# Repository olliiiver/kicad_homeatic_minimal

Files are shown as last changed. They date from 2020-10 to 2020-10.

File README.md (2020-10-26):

## Homematic minimal PCB

A minimal PCB to build hardware devices for Homematic / BidCoS networks.

PINs (A0x - D0x, GND, 3v3) are compatible to 2.54mm prototype perfboards.

Upload is possible via Serial (FTDI,etc) and ISP (J3).

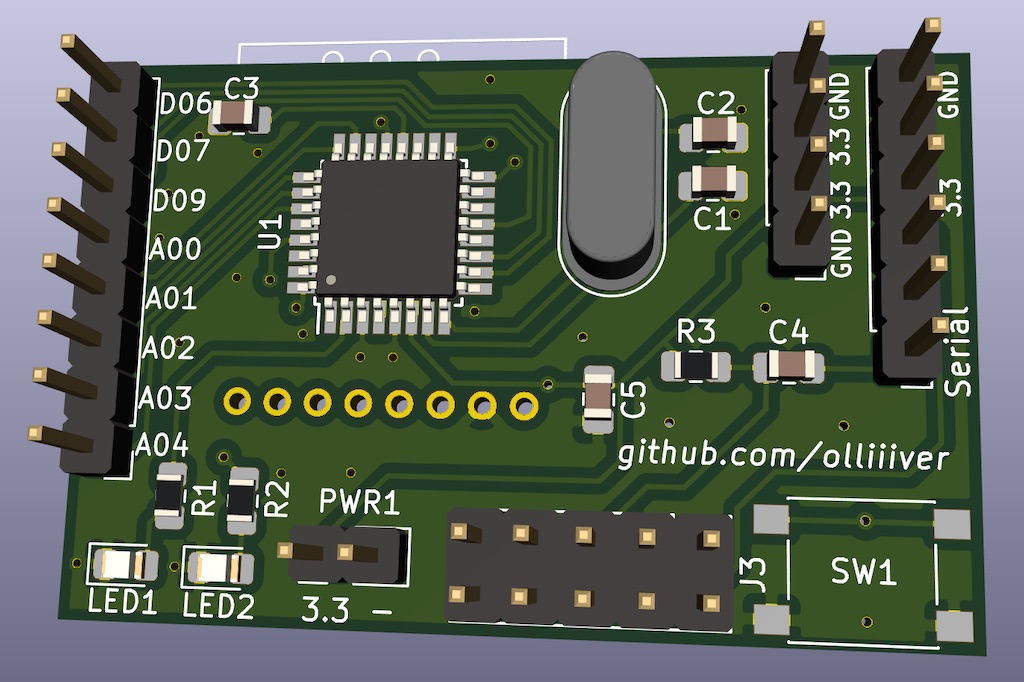
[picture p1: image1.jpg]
RENDERED


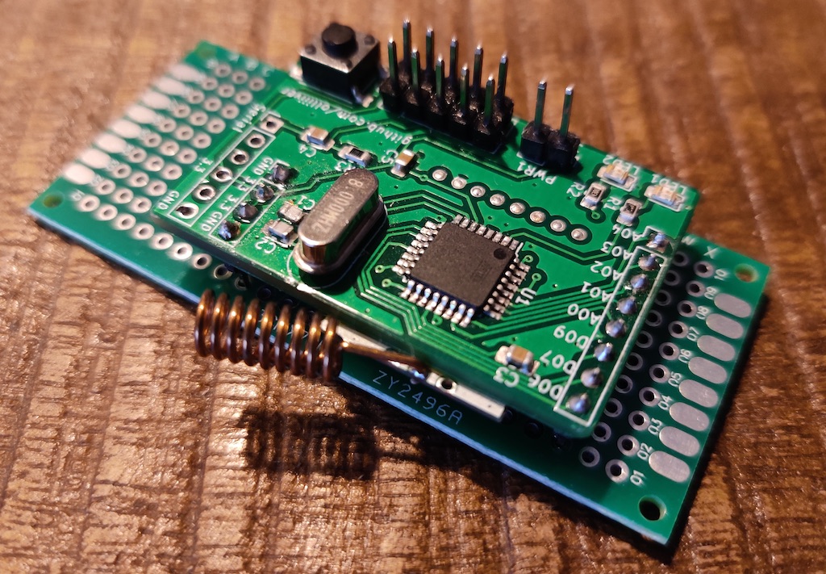
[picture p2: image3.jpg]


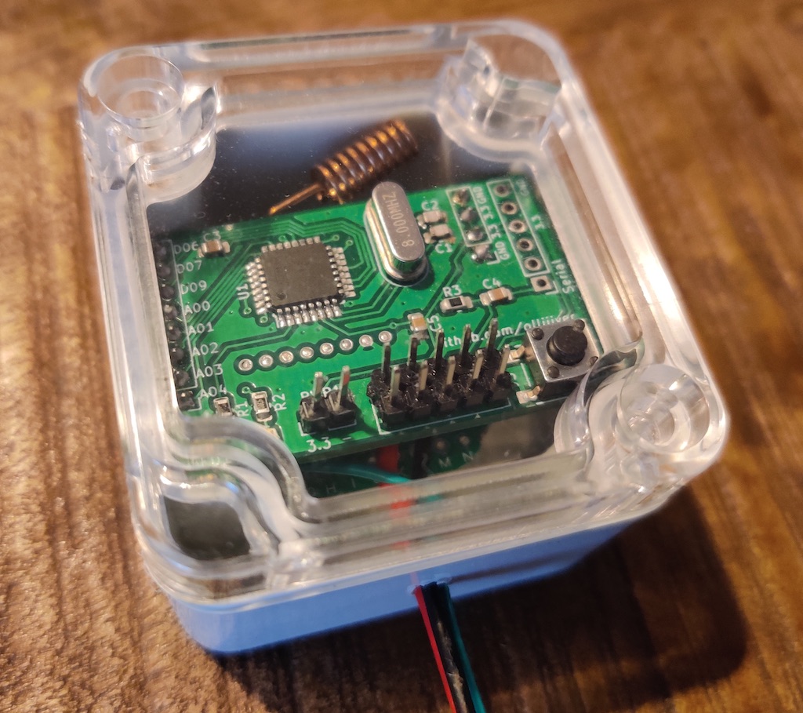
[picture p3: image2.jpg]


## BOM

- Case: RND 455-00192
  https://www.reichelt.de/polycarbonate-box-w-clear-lid-rnd-455-00192-p193406.html

- ATmega328P-AU
  http://ww1.microchip.com/downloads/en/DeviceDoc/Atmel-7810-Automotive-Microcontrollers-ATmega328P_Datasheet.pdf
  https://www.reichelt.de/atmega-avr-risc-controller-tqfp-32-atmega-328p-au-p119684.html
  
- Switch: RND 210-00204
  https://www.reichelt.de/pcb-tactile-switches-rnd-210-00204-p226425.html
  
- C 0805: 22 pF, 100pF
  https://www.reichelt.de/mlcc-0805-22-pf-200-v-5-rnd-1500805n2203-p226114.html
    
- LED 0805
  https://www.reichelt.de/led-smd-0805-green-7-1-mcd-160-oso-lgr971-p231718.html

  - R 0805: 330 Ohm, 1k Ohm, etc

  - CC1101 module from ebay

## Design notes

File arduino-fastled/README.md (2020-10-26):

## Implementation to use WS2801 stripes as a Homematic dimmer device

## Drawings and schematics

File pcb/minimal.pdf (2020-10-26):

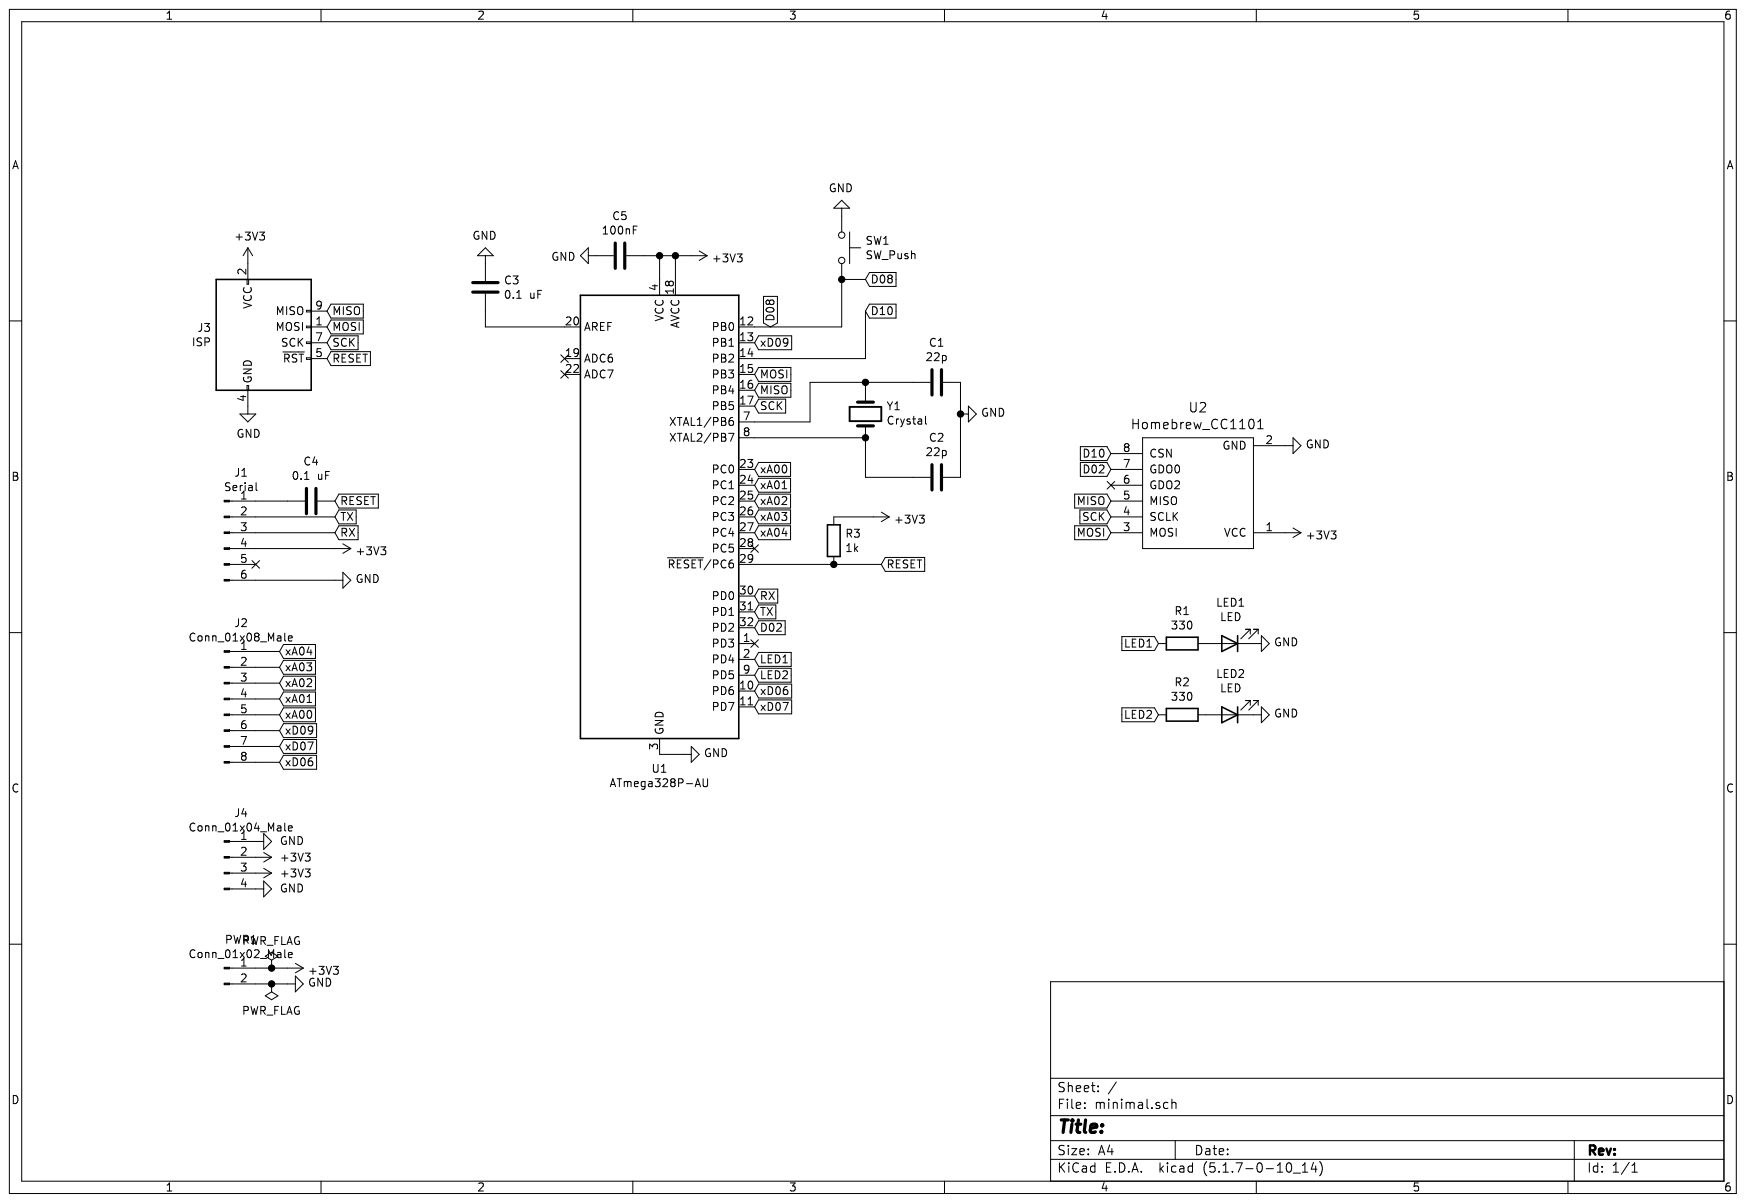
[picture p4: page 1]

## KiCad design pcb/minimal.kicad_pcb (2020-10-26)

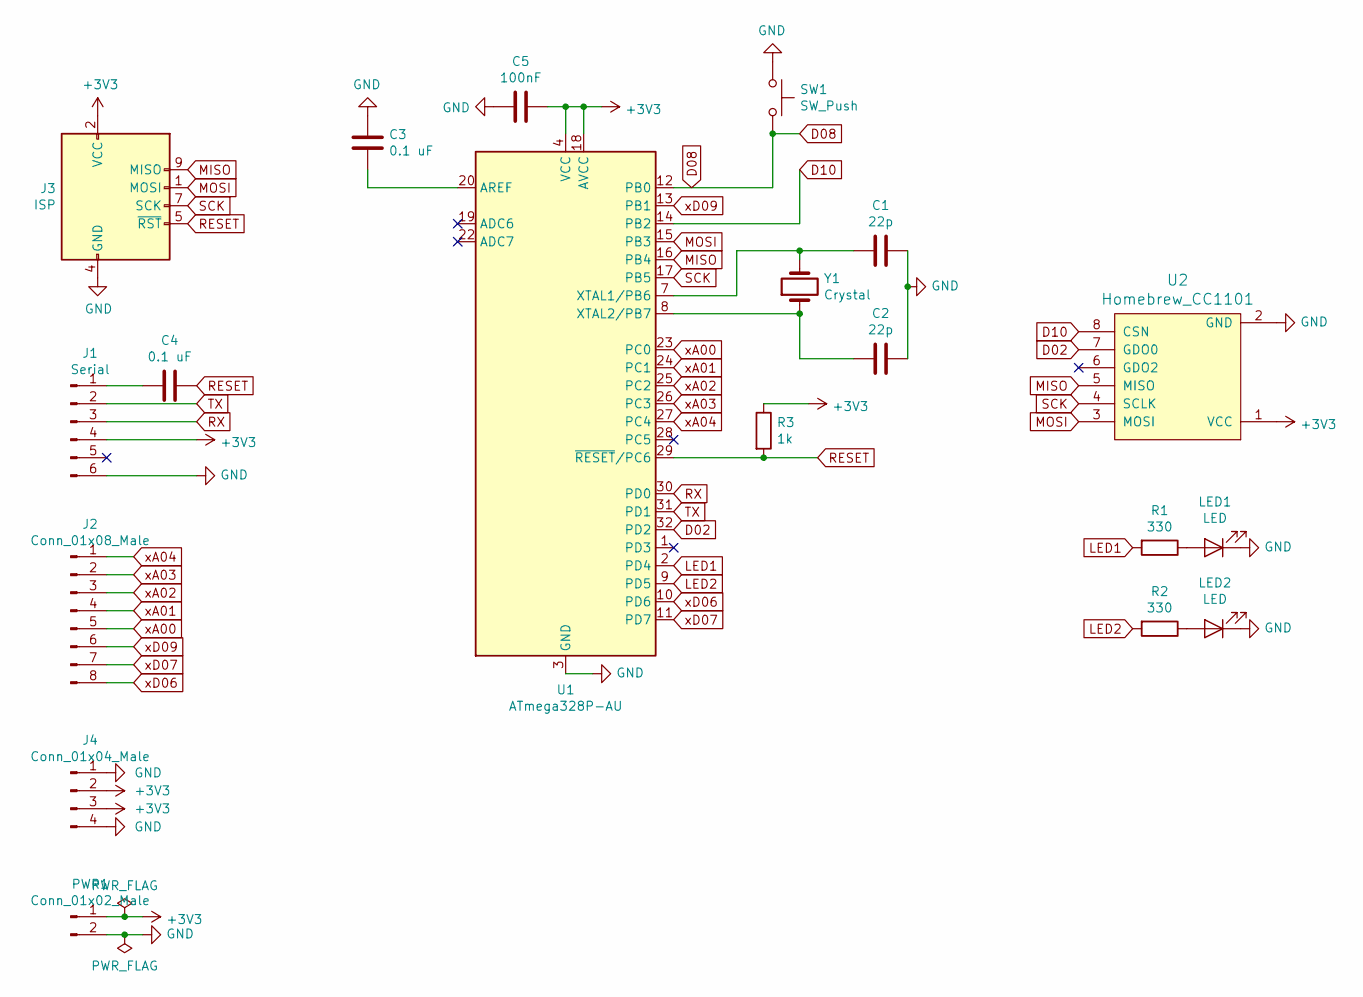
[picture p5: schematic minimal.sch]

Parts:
C1, C2: 22p; C_0805_2012Metric_Pad1.15x1.40mm_HandSolder
C3, C4: 0.1 uF; C_0805_2012Metric_Pad1.15x1.40mm_HandSolder
C5: 100nF; C_0805_2012Metric_Pad1.15x1.40mm_HandSolder
J1: Serial; PinHeader_1x06_P2.54mm_Vertical
J2: Conn_01x08_Male; PinHeader_1x08_P2.54mm_Vertical
J3: ISP; PinHeader_2x05_P2.54mm_Vertical
J4: Conn_01x04_Male; PinHeader_1x04_P2.54mm_Vertical
LED1, LED2: LED; LED_0805_2012Metric_Pad1.15x1.40mm_HandSolder
PWR1: Conn_01x02_Male; PinHeader_1x02_P2.54mm_Vertical
R1, R2: 330; R_0805_2012Metric_Pad1.15x1.40mm_HandSolder
R3: 1k; R_0805_2012Metric_Pad1.15x1.40mm_HandSolder
SW1: SW_Push; SW_Push_1P1T_NO_6x6mm_H9.5mm
U1: ATmega328P-AU; TQFP-32_7x7mm_P0.8mm
U2: Homebrew_CC1101; cc1101
Y1: Crystal; Crystal_HC49-4H_Vertical

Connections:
+3V3: C5.1, J1.4, J3.2 (VCC), J4.2, J4.3, PWR1.1, R3.1, U1.4 (VCC), U1.6 (VCC), U1.18 (AVCC), U2.1 (VCC)
D02: U1.32 (PD2), U2.7 (GDO0)
D08: SW1.2, U1.12 (PB0)
D10: U1.14 (PB2), U2.8 (CSN)
GND: C1.1, C2.1, C3.1, C5.2, J1.6, J3.4 (GND), J3.6 (GND), J3.8 (GND), J3.10 (GND), J4.1, J4.4, LED1.1 (K), LED2.1 (K), PWR1.2, SW1.1, U1.3 (GND), U1.5 (GND), U1.21 (GND), U2.2 (GND)
LED1: R1.2, U1.2 (PD4)
LED2: R2.2, U1.9 (PD5)
MISO: J3.9 (MISO), U1.16 (PB4), U2.5 (MISO)
MOSI: J3.1 (MOSI), U1.15 (PB3), U2.3 (MOSI)
unnamed: C1.2, U1.7 (XTAL1/PB6), Y1.2
unnamed: C2.2, U1.8 (XTAL2/PB7), Y1.1
unnamed: C3.2, U1.20 (AREF)
unnamed: C4.2, J1.1
unnamed: LED1.2 (A), R1.1
unnamed: LED2.2 (A), R2.1
RESET: C4.1, J3.5 (~RST), R3.2, U1.29 (~RESET~/PC6)
RX: J1.3, U1.30 (PD0)
SCK: J3.7 (SCK), U1.17 (PB5), U2.4 (SCLK)
TX: J1.2, U1.31 (PD1)
xA00: J2.5, U1.23 (PC0)
xA01: J2.4, U1.24 (PC1)
xA02: J2.3, U1.25 (PC2)
xA03: J2.2, U1.26 (PC3)
xA04: J2.1, U1.27 (PC4)
xD06: J2.8, U1.10 (PD6)
xD07: J2.7, U1.11 (PD7)
xD09: J2.6, U1.13 (PB1)

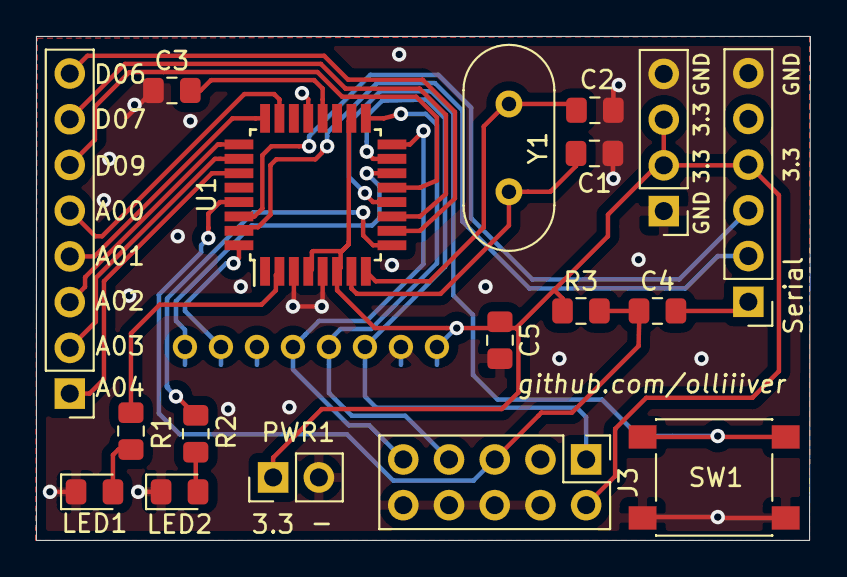
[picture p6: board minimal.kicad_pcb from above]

Board: 2 copper layers, 43.0 x 28.0 mm, 19 parts (1 on the bottom side), 27 nets.

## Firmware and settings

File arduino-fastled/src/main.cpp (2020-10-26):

#include <arduino.h>
#include <FastLED.h>

// LED STRIPE PIN
#define DATA_PIN 6
#define NUM_LEDS 49
#define MAX_BRIGHTNESS 255 // 0-255

int randColor;

CRGB leds[NUM_LEDS];
CRGB incomes[NUM_LEDS];

#define EI_NOTEXTERNAL
//#include <EnableInterrupt.h>
#include <AskSinPP.h>
#include <LowPower.h>

#include <Dimmer.h>

// we use a Pro Mini
// Arduino pin for the LED
// D4 == PIN 4 on Pro Mini
#define LED_PIN 4

// Arduino pin for the config button
// B0 == PIN 8 on Pro Mini
#define CONFIG_BUTTON_PIN 8

// number of available peers per channel
#define PEERS_PER_CHANNEL 4

// all library classes are placed in the namespace 'as'
using namespace as;

const struct DeviceInfo PROGMEM devinfo = {
    {0x11,0x12,0x22},       // Device ID
    "DIMX111111",           // Device Serial
//    {0x00,0x67},            // Device Model
    {0x00,0xF4},            // Device Model
    0x25,                   // Firmware Version
    as::DeviceType::Dimmer, // Device Type
    {0x01,0x00}             // Info Bytes
};


// ---

template <class HalType,class DimmerType>
class I2CDimmerControl {
private:
  DimmerType& dimmer;
  uint8_t physical[DimmerType::channelCount/DimmerType::virtualCount];
  uint8_t factor[DimmerType::channelCount/DimmerType::virtualCount];
  uint8_t counter;
  uint8_t color;
  uint8_t overloadcounter;

  class ChannelCombiner : public Alarm {
    I2CDimmerControl<HalType,DimmerType>& control;
  public:
    ChannelCombiner (I2CDimmerControl<HalType,DimmerType>& d) : Alarm(0), control(d) {}
    virtual ~ChannelCombiner () {}
    virtual void trigger (AlarmClock& clock) {
      control.updatePhysical();
      set(millis2ticks(10));
      clock.add(*this);
    }
  } cb;

public:
  I2CDimmerControl (DimmerType& dim) : dimmer(dim), cb(*this) {}
  ~I2CDimmerControl () {}

  uint8_t channelCount  () { return DimmerType::channelCount; }
  uint8_t virtualCount  () { return DimmerType::virtualCount; }
  uint8_t physicalCount () { return DimmerType::channelCount/DimmerType::virtualCount; }

  void firstinit () {
    for( uint8_t i=1; i<=channelCount(); ++i ) {
      if( i <= physicalCount() ){
        dimmer.dimmerChannel(i).getList1().logicCombination(LOGIC_OR);
      }
      else {
        dimmer.dimmerChannel(i).getList1().logicCombination(LOGIC_INACTIVE);
      }
    }

  }

  bool init (HalType& hal) {
    bool first = dimmer.init(hal);
    if( first == true ) {
      firstinit();
    }
//    Wire.begin( );
//    set(0,0);
    for( uint8_t i=0; i<physicalCount(); ++i ) {
        physical[i] = 0;
        factor[i] = 200; // 100%
    }
    initChannels();
    cb.trigger(sysclock);
    return first;
  }

  void initChannels () {
    for( uint8_t i=1; i<=physicalCount(); ++i ) {
      for( uint8_t j=i; j<=channelCount(); j+=physicalCount() ) {
        dimmer.dimmerChannel(j).setPhysical(physical[i-1]);
        bool powerup = dimmer.dimmerChannel(j).getList1().powerUpAction();
        dimmer.dimmerChannel(j).setLevel(powerup == true ? 200 : 0,0,0xffff);
      }
    }
  }

  void hsvToRgb(double h, double s, double v, byte rgb[]) {
    double r, g, b;

    int i = int(h * 6);
    double f = h * 6 - i;
    double p = v * (1 - s);
    double q = v * (1 - f * s);
    double t = v * (1 - (1 - f) * s);

    switch(i % 6){
        case 0: r = v, g = t, b = p; break;
        case 1: r = q, g = v, b = p; break;
        case 2: r = p, g = v, b = t; break;
        case 3: r = p, g = q, b = v; break;
        case 4: r = t, g = p, b = v; break;
        case 5: r = v, g = p, b = q; break;
    }

    rgb[0] = r * 255;
    rgb[1] = g * 255;
    rgb[2] = b * 255;
  }

  void set (uint8_t value, uint8_t color) {
    DPRINT("Value "); DDEC(value); DPRINT(" -- "); DDEC(color);DPRINT("\n");
    byte rgb[3];
    if (value < 1) {
//      leds.off();
      LEDS.showColor(CRGB(0, 0,0));
    } else if (color < 190) {
      hsvToRgb(color / 200.0, 1,value / 200.0, rgb);
      DPRINT("R: "); DDEC(rgb[0]); DPRINT("G: "); DDEC(rgb[1]); DPRINT("B: "); DDEC(rgb[2]); DPRINT("\n");
      LEDS.showColor(CRGB(rgb[0], rgb[1], rgb[2]));
//      leds.set_brightness(4, rgb[0]); /* red PIN = 11 */
//      leds.set_brightness(5, rgb[1]); /* green PIN = 12 */
//      leds.set_brightness(6, rgb[2]); /* blue  = PIN 13 */
//      leds.set_brightness(3, 0); /* ww PIN = 9 */
//      leds.set_brightness(2, 0); /* cw PIN = 8 */
    } else if (color < 195) {
//      leds.set_brightness(4, 100); /* red PIN = 11 */
//      leds.set_brightness(5, 100); /* green PIN = 12 */
//      leds.set_brightness(6, 10); /* blue  = PIN 13 */ 
//      leds.set_brightness(3, value); /* ww PIN = 9 */
//      leds.set_brightness(2, 0); /* cw PIN = 8 */
    } else {
//      leds.set_brightness(4, 100); /* red PIN = 11 */
//      leds.set_brightness(5, 100); /* green PIN = 12 */
//      leds.set_brightness(6, 100); /* blue  = PIN 13 */ 
//      leds.set_brightness(3, 0); /* ww PIN = 9 */
//      leds.set_brightness(2, value); /* cw PIN = 8 */
    }
  }
  
  void updatePhysical () {
    // DPRINT("update phys ");
    // DPRINT("Pin ");DHEX(pin);DPRINT("  Val ");DHEXLN(calcPwm());
    uint8_t c = dimmer.dimmerChannel(2).status();
    for( uint8_t i=0; i<physicalCount(); ++i ) {
      uint8_t value = (uint8_t)combineChannels(i+1);
      value = (((uint16_t)factor[i] * (uint16_t)value) / 200);
      if( physical[i] != value || c != color) {
        // DPRINT("Ch: ");DDEC(i+1);DPRINT(" Phy: ");DDECLN(value);
        physical[i]  = value;
        color = c;
        set(physical[i], color);
      }
    }
  }

  uint16_t combineChannels (uint8_t start) {
    uint16_t value = 0;
    for( uint8_t i=start; i<=channelCount(); i+=physicalCount() ) {
      uint8_t level = dimmer.dimmerChannel(i).status();
      switch( dimmer.dimmerChannel(i).getList1().logicCombination() ) {
      default:
      case LOGIC_INACTIVE:
        break;
      case LOGIC_OR:
        value = value > level ? value : level;
        break;
      case LOGIC_AND:
        value = value < level ? value : level;
        break;
      case LOGIC_XOR:
        value = value==0 ? level : (level==0 ? value : 0);
        break;
      case LOGIC_NOR:
        value = 200 - (value > level ? value : level);
        break;
      case LOGIC_NAND:
        value = 200 - (value < level ? value : level);
        break;
      case LOGIC_ORINVERS:
        level = 200 - level;
        value = value > level ? value : level;
        break;
      case LOGIC_ANDINVERS:
        level = 200 - level;
        value = value < level ? value : level;
        break;
      case LOGIC_PLUS:
        value += level;
        if( value > 200 ) value = 200;
        break;
      case LOGIC_MINUS:
        if( level > value ) value = 0;
        else value -= level;
        break;
      case LOGIC_MUL:
        value = value * level / 200;
        break;
      case LOGIC_PLUSINVERS:
        level = 200 - level;
        value += level;
        if( value > 200 ) value = 200;
        break;
        break;
      case LOGIC_MINUSINVERS:
        level = 200 - level;
        if( level > value ) value = 0;
        else value -= level;
        break;
      case LOGIC_MULINVERS:
        level = 200 - level;
        value = value * level / 200;
        break;
      case LOGIC_INVERSPLUS:
        value += level;
        if( value > 200 ) value = 200;
        value = 200 - value;
        break;
      case LOGIC_INVERSMINUS:
        if( level > value ) value = 0;
        else value -= level;
        value = 200 - value;
        break;
      case LOGIC_INVERSMUL:
        value = value * level / 200;
        value = 200 - value;
        break;
      }
    }
    // DHEXLN(value);
    return value;
  }
   
  void setOverload (bool overload=false) {
      counter++;
      if ( overload ){
          overloadcounter++;
          
      }
      for( uint8_t i=1; i<=physicalCount(); ++i ) {
        typename DimmerType::DimmerChannelType& c = dimmer.dimmerChannel(i);
        if ( counter > 5 ){
            if((counter - overloadcounter) <= 2 ){
              factor[i-1] = 0;
              c.overload(true);
          }
          else{
             counter = 0;
             overloadcounter = 0;
          }
          
        }
        else if ( c.getoverload()) {
              c.overload(false);
              factor[i-1] = 200;
        }
     }
  }

  void setTemperature (uint16_t temp) {
    uint8_t t = temp/10;
    for( uint8_t i=1; i<=physicalCount(); ++i ) {
      typename DimmerType::DimmerChannelType& c = dimmer.dimmerChannel(i);
      if( c.getList1().overTempLevel() <= t ) {
        factor[i-1] = 0; // overtemp -> switch off
        c.overheat(true);
        c.reduced(false);
      }
      else if( c.getList1().reduceTempLevel() <= t ) {
        factor[i-1] = c.getList1().reduceLevel();
        c.overheat(false);
        c.reduced(true);
      }
      else {
        factor[i-1] = 200; // 100%
        c.overheat(false);
        c.reduced(false);
      }
    }
  }
};


// ---

/**
 * Configure the used hardware
 */
typedef AvrSPI<10,11,12,13> SPIType;
typedef Radio<SPIType,2> RadioType;
typedef StatusLed<LED_PIN> LedType;
typedef AskSin<LedType,NoBattery,RadioType> HalType;
typedef DimmerChannel<HalType,PEERS_PER_CHANNEL> ChannelType;
typedef DimmerDevice<HalType,ChannelType,3,3> DimmerType;

HalType hal;
DimmerType sdev(devinfo,0x20);

I2CDimmerControl<HalType,DimmerType> control(sdev);
ConfigToggleButton<DimmerType> cfgBtn(sdev);

void setup () {
  DINIT(57600,ASKSIN_PLUS_PLUS_IDENTIFIER);
  if( control.init(hal) ) {
    // first init - setup connection between config button and first channel
    sdev.channel(1).peer(cfgBtn.peer());
  }
  buttonISR(cfgBtn,CONFIG_BUTTON_PIN);
  sdev.initDone();

  FastLED.addLeds<WS2812B, DATA_PIN, GRB>(leds, NUM_LEDS);
  FastLED.setTemperature( CRGB(255, 180, 150) );
  FastLED.setBrightness( MAX_BRIGHTNESS );
  LEDS.showColor(CRGB(150, 100, 100));
}

void loop() {
  bool worked = hal.runready();
  bool poll = sdev.pollRadio();
  if( worked == false && poll == false ) {
    hal.activity.savePower<Idle<true> >(hal);
  }
}

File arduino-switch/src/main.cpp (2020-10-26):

#define CFG_STEPUP_BYTE 0x00
#define CFG_STEPUP_OFF  0x00
#define CFG_STEPUP_ON   0x01

#define CFG_BAT_LOW_BYTE 0x01
#define CFG_BAT_CRITICAL_BYTE 0x02

// define device configuration bytes
#define DEVICE_CONFIG CFG_STEPUP_OFF,22,19

#define EI_NOTEXTERNAL
#include <EnableInterrupt.h>
#include <AskSinPP.h>
#include <LowPower.h>

#include <Register.h>
#include <ThreeState.h>

// we use a Pro Mini
// Arduino pin for the LED
// D4 == PIN 4 on Pro Mini
#define LED1_PIN 4
#define LED2_PIN 5
// Arduino pin for the config button
// B0 == PIN 8 on Pro Mini
#define CONFIG_BUTTON_PIN 8

#define SENS1_PIN 14
#define SENS2_PIN 15
#define SABOTAGE_PIN 16

// activate additional open detection by using a third sensor pins
// #define SENS3_PIN 16
// #define SABOTAGE_PIN 0

// number of available peers per channel
#define PEERS_PER_CHANNEL 10

// all library classes are placed in the namespace 'as'
using namespace as;

// define all device properties
const struct DeviceInfo PROGMEM devinfo = {
    {0x09,0x56,0x34},       // Device ID
    "papa222111",           // Device Serial
    {0x00,0xC3},            // Device Model
    0x22,                   // Firmware Version
    as::DeviceType::ThreeStateSensor, // Device Type
    {0x01,0x00}             // Info Bytes
};

typedef NoBattery BattSensType;

/**
 * Configure the used hardware
 */
typedef AvrSPI<10,11,12,13> SPIType;
typedef Radio<SPIType,2> RadioType;
typedef DualStatusLed<LED2_PIN,LED1_PIN> LedType;
typedef AskSin<LedType,BatterySensor,RadioType> BaseHal;
class Hal : public BaseHal {
public:
  void init (const HMID& id) {
    BaseHal::init(id);
  }
} hal;

DEFREGISTER(Reg0,DREG_INTKEY,DREG_CYCLICINFOMSG,MASTERID_REGS,DREG_TRANSMITTRYMAX,DREG_SABOTAGEMSG)
class RHSList0 : public RegList0<Reg0> {
public:
  RHSList0(uint16_t addr) : RegList0<Reg0>(addr) {}
  void defaults () {
    clear();
    cycleInfoMsg(true);
    transmitDevTryMax(6);
    sabotageMsg(true);
  }
};

DEFREGISTER(Reg1,CREG_AES_ACTIVE,CREG_MSGFORPOS,CREG_EVENTDELAYTIME,CREG_LEDONTIME,CREG_TRANSMITTRYMAX)
class RHSList1 : public RegList1<Reg1> {
public:
  RHSList1 (uint16_t addr) : RegList1<Reg1>(addr) {}
  void defaults () {
    clear();
    msgForPosA(1); // CLOSED
    msgForPosB(2); // OPEN
    msgForPosC(3); // TILTED
    // aesActive(false);
    // eventDelaytime(0);
    ledOntime(100);
    transmitTryMax(6);
  }
};


typedef ThreeStateChannel<Hal,RHSList0,RHSList1,DefList4,PEERS_PER_CHANNEL> ChannelType;

class RHSType : public ThreeStateDevice<Hal,ChannelType,1,RHSList0> {
public:
  typedef ThreeStateDevice<Hal,ChannelType,1,RHSList0> TSDevice;
  RHSType(const DeviceInfo& info,uint16_t addr) : TSDevice(info,addr) {}
  virtual ~RHSType () {}

 // virtual void configChanged () {
 //   TSDevice::configChanged();
 //   // set battery low/critical values
 //   battery().low(getConfigByte(CFG_BAT_LOW_BYTE));
 //   battery().critical(getConfigByte(CFG_BAT_CRITICAL_BYTE));
 //    #ifndef BATTERY_IRQ
 //    // set the battery mode
 //    battery().meter().sensor().mode(getConfigByte(CFG_STEPUP_BYTE));
 //    #endif
 //  }
};

RHSType sdev(devinfo,0x20);
ConfigButton<RHSType> cfgBtn(sdev);

const uint8_t posmap[4] = {Position::State::PosB,Position::State::PosC,Position::State::PosA,Position::State::PosB};

void setup () {
  DINIT(57600,ASKSIN_PLUS_PLUS_IDENTIFIER);
  sdev.init(hal);
  buttonISR(cfgBtn,CONFIG_BUTTON_PIN);
  sdev.channel(1).init(SENS1_PIN,SENS2_PIN,SABOTAGE_PIN,posmap);
  sdev.initDone();
    
  // measure battery every 1h
  // hal.battery.init(seconds2ticks(60UL*60),sysclock);
}

void loop() {
  bool worked = hal.runready();
  bool poll = sdev.pollRadio();
  if( worked == false && poll == false ) {
    // if nothing to do - go sleep
    hal.sleep<>();
  }
}
